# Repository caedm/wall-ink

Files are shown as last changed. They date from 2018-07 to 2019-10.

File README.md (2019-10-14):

# Introduction
Wall-ink was designed from the ground up to be a scalable, [secure](https://github.com/caedm/wall-ink/wiki/Device-security), and completely open solution to display conference room schedules at a university.  The product could, however, be developed to display other images for advertising, directions, staff directories, a weather station, retail pricing, etc.  Currently, the [wall-ink-server](https://github.com/caedm/wall-ink-server) can display schedules from the open source [Booked scheduler](https://www.bookedscheduler.com), any web published iCal file (Outlook / Exchange), and the Google Calendar API.  It can also [rotate through a collection of static images](https://github.com/caedm/wall-ink-server/wiki/Plugin-architecture#static-images-plugin).  With [additional development](https://github.com/caedm/wall-ink-server/wiki/Coding-a-new-plugin), other scheduler integrations or functions are possible.  The hardware simply displays whatever image it is given when it checks in with a wall-ink-server.  Development for putting images on the e-ink screen is made simpler by [allowing the image creation processing](https://github.com/caedm/wall-ink-server/wiki/Wall-ink-image-formats-and-image-handling) to occur on the server side, and not on the device.  Server-side image creation was a design choice for deploying a large fleet of these devices across mulitple buildings.  This way, changes can be made to what the devices are displaying without having to update firmware on dozens or hundreds of devices.  To date, we are aware of several other groups who have successfully written their own server-side software for wall-ink devices in various languages.  Links to other related wall-ink projects are found on the [additional wall ink projects](https://github.com/caedm/wall-ink/wiki/Additional-wall-ink-projects) page.



The original design parameters of this project were to display a room schedule electronically with no wires, at the cheapest possible price point.  No Ethernet, no power wires, in a low-cost footprint.  The resulting project has produced a AA powered WiFi E-ink device for under $100 (US), when parts are purchased in bulk, where the [batteries last a year or two](https://github.com/caedm/wall-ink/wiki/Circuit#batteries).  

The wall-ink project along with the [Wall-Ink-Server](https://github.com/caedm/wall-ink-server) includes everything necessary to build the entire e-ink display system. 

# Summary
The wall-ink project has several components:

* [Circuit and electronics](https://github.com/caedm/wall-ink/wiki/circuit), including Eagle schematic, PCB layout and gerber files
* List of necessary [parts](https://github.com/caedm/wall-ink/wiki/partslist) to build the project
* Arduino IDE [Firmware](https://github.com/caedm/wall-ink/wiki/firmware) for the ESP8266 microcontroller
* CAD files to 3D print the [Case](https://github.com/caedm/wall-ink/wiki/firmware)
* See the [Wall-Ink-Server](https://github.com/caedm/wall-ink-server) project for server side code


# FAQ

## What hardware does wall-ink run on and where do I get it?
The wall-ink project is a hardware, firmware, and software build.  To date, we are not aware of any off-the-shelf commercial products that will do everything that the [wall-ink device](https://github.com/caedm/wall-ink/wiki/7.5%22-Wall-ink-device) does.  There are plenty of ESP8266 devices out there, including ones that sleep, but the hardware as described here is specifically designed to run the wall-ink firmware, sleep, use very little power, fit in the supplied 3D printable case, and update a Waveshare e-ink screen.

## Can I hire you to make the hardware for me?
Due to conflict of interest policies at the University we work for, we are not available for hire to create hardware for you, or to customize software features for you.  That being said, we have uploaded all of the design files and code, and reasonable documentation to do it on your own.  Many people have created this project on their own with positive results.

## What is an ESP8266 and why did you choose that microprocessor?
The [ESP8266 by Espressif Systems](https://en.wikipedia.org/wiki/ESP8266) is similar to an Arduino, but has 10uA deep-sleep function and built-in WiFi with a full TCP/IP stack.  The ESP8266 is also low cost, and fully compatible with the Arduino IDE.  So for under $3, you get a microprocessor that is perfect for this project.

## Why e-ink?  Is it a touch display?
In order to run the device for over a year on a set of AA batteries, we needed to use the lowest power screen possible. Since e-ink screens can hold their image even with the power removed, this is by far the lowest power option out there.  To keep the cost down, the type of [E-ink screens](https://en.wikipedia.org/wiki/E-ink) we chose from Waveshare / Good Display does not have touch screen capability.

## What e-ink screens are supported?
The real limitation of screen resolution support is the RAM available on the esp8266.  Some server-side plugins like the static image plugin and the simple text plugin can handle any screen size dynamically.  Other plugins like the booked and google plugins that use the general scheduling functions are hard-coded for Waveshare 7.5" screens at 640x384 and Waveshare 4.2" screens at 400x300 pixels.  There is currently no support for color displays.  We believe that there would be insufficient memory to support the larger color screens using the current method that the firmware has been coded.  The color screens also take a significant amount of time to update, and the batteries would not last sufficiently long for our use-case, so we did not pursue this option.



## Why does a wall-ink device require a server?
Using a central server for controlling what is displayed on wall-ink devices was a design decision to ease the management of large numbers of devices.  If you only need to manage one e-ink device, running a server component might be overkill, but with dozens or hundreds of devices in the field, it is essential.  Tweaking what is being displayed on 100 or more screens can be done by changing a parameter on a website rather than updating firmware on dozens of devices across the enterprise.  Any wall-ink device pointed to a wall-ink-server can be configured do display ANY image at any time the next time in checks in.  There are also central management features such as looking at error logs, Nagios monitoring, voltage monitoring, and other such high-level tools, all made possible through this architecture.

## Can Wall-ink devices talk to a webserver using https?
The short answer is no.  There are libraries available for an esp8266 to talk to a webserver securely, but [there is not enough RAM onboard](https://github.com/caedm/wall-ink/wiki/Wall-ink-Memory#ram) to run the neccessary encryption code.  If security is a concern, please refer to the wiki articles about [device security](https://github.com/caedm/wall-ink/wiki/Device-security) and [wall-ink server security considerations](https://github.com/caedm/wall-ink-server/wiki/Security-considerations#image-security).

## Will a Wall-ink device connect to enterprise WiFi?
The short answer is maybe.  The ESP8266 WiFi client firmware has been tested to work with WPA2-PSK but does not appear to work with WPA2 Enterprise (including Eduroam). Some enterprises offer an additional "guest" network SSID with limited internal connectivity to handle embedded IOT devices as a solution to this problem.  Before going to the trouble of building this whole project and purchasing a screen, you could purchase an ESP8266 devkit and try connecting to your company's WiFi. 

## What skills and tools  will I need to complete this project?
Some basic electronics experience could be useful if building a [development board prototype](https://github.com/caedm/wall-ink/wiki/development-board-prototype). Building an actual [wall-ink device](https://github.com/caedm/wall-ink/wiki/wall-ink-device) will require some basic soldering and 3d printing, and some electronics experience would be useful to help identify and purchase all the right [parts](https://github.com/caedm/wall-ink/wiki/partslist). The software end of the project will require the use of the Arduino IDE to flash the firmware, and a simple web server to run the [wall-ink-server](https://github.com/caedm/wall-ink-server). The wall-ink-server project has only been tested with Apache, but should work with other server software that supports PHP.

# Getting started
To get a wall-ink device up and running, you will need to build a hardware device and flash it with the latest firmware.  Then you will need to install a [small web service] to host the content for your device to display.  Last, you will need to [configure your new hardware device](https://github.com/caedm/wall-ink/wiki/Admin-mode) to access your wireless network and find your webserver.
## Building the hardware
There are a couple different methods to get started with wall-ink hardware
### Option 1: 
Purchase an esp8266 development board, and a Waveshare e-ink display with HAT and make a [development board prototype](https://github.com/caedm/wall-ink/wiki/Development-board-prototype).  This method will get you up and running quickly with a minimal cost for a proof-of-concept project.  You will be able to power and flash the development board via USB from your computer.  These development boards are designed to be easy to use, but are not meant for battery operated production devices.  The integrated USB to serial chip on the development board alone will drain your batteries in a matter of days.  If you want your device to operate for years on end off of batteries, you will need to build the wall-ink circuit that has been specifically designed for low power draw.



### Option 2:  
Buy all the [loose parts](https://github.com/caedm/wall-ink/wiki/partslist) and solder them to the [printed circuit board](https://github.com/caedm/wall-ink/wiki/Printed-Circuit-Board).  You will also need to [3d print a case](https://github.com/caedm/wall-ink/wiki/7.5%22-Wall-ink-case) for the project.  If you want to start with the real thing, there is no reason why you can't just go straight to it.



## Building and flashing the firmware on to the ESP8266
See the detailed instructions in the [building and flashing firmware wiki article](https://github.com/caedm/wall-ink/wiki/firmware#Building) for instructions on uploading the firmware.

## Install and configure the web server code
See the documentation for the [wall-ink-server](https://github.com/caedm/wall-ink-server) companion project.  If desired, you could write a much simpler server that was not designed for an enterprise as long as it returned files in the correct ["wink format"](https://github.com/caedm/wall-ink-server/wiki/Wall-ink-image-formats-and-image-handling#wink-file-format).  The wall-ink-server project is designed to handle hundreds of devices using various plugins to collect data and present images to the screens.  It includes Nagios monitoring scripts, battery monitors and other tools to handle a large fleet of wall-ink devices.
## Configure the device
Use [Admin mode](https://github.com/caedm/wall-ink/wiki/Admin-mode) to set up the wireless client, the image key, and the URL to get images from.

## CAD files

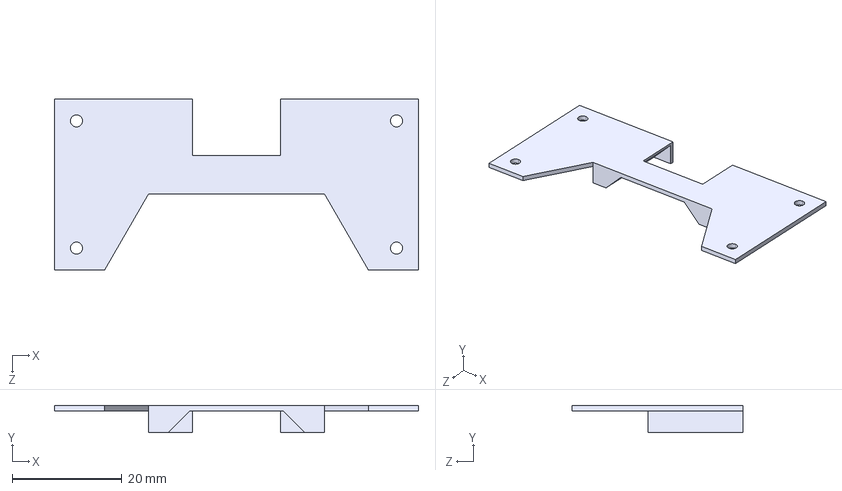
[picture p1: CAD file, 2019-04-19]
case/hat_adapter.STEP
66.2 x 5.00 x 31.1 mm

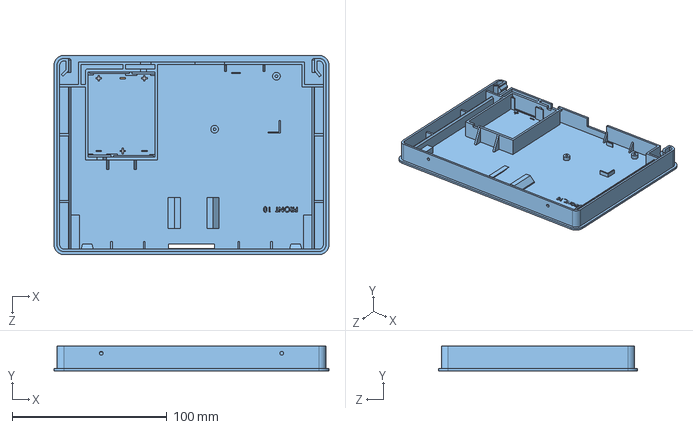
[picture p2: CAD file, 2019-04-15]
case/front.STEP
178.0 x 16.0 x 129.0 mm

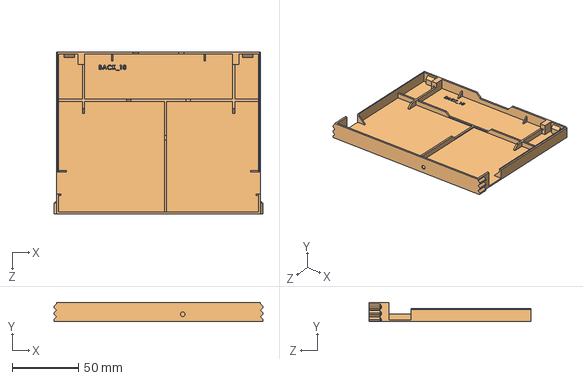
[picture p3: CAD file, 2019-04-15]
case/back.STEP
157.9 x 14.4 x 122.3 mm

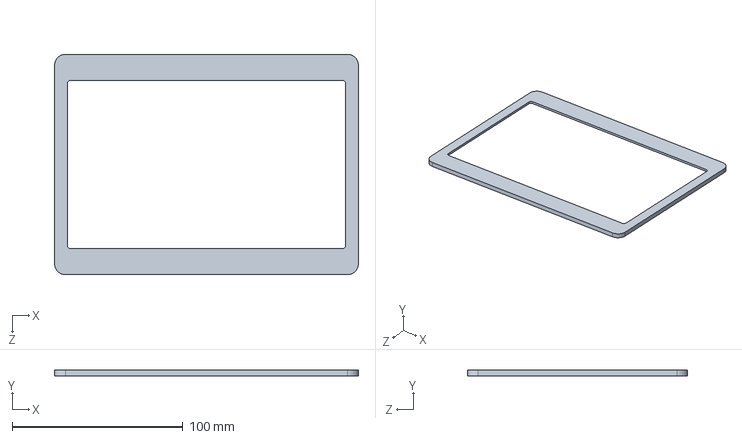
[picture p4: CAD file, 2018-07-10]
case/faceplate.SLDPRT
178.0 x 3.30 x 129.0 mm

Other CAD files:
case/back.IGS
case/back.SLDPRT
case/back.STL
case/faceplate.STL
case/front.IGS
case/front.SLDPRT
case/front.STL
case/hat_adapter.IGS
case/hat_adapter.SLDPRT
case/hat_adapter.STL

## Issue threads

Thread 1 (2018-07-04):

Need to upload hardware

jdeananderson, 2018-07-04:
Need to upload the Eagle Schematic, board layout and gerber files.

AndersenJ, 2018-07-09:
Finished as of 576c2fc

Closed 2018-07-09.

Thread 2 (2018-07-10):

7.5" layout for battery savings

jdeananderson, 2018-07-10:
Feature request:  There is a 4" layout that does not have a time "tick" at the bottom of the screen, and that doesn't update the start time of an event as time progresses.  I would like a 7.5" layout that does the same thing to save updates and therefore battery life.

AndersenJ, 2018-07-10:
This has been implemented on https://github.com/caedm/wall-ink-server

Closed 2018-07-10.

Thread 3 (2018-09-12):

DEFAULT_IMAGE_KEY not writing to memory when changed in Firmware

emdarcher, 2018-09-12:
In the code I changed the value of DEFAULT_IMAGE_KEY in stream_screen.ino, compiled, and re-flashed the firmware with said code. When the device reboots it still uses the old image key. Tested by entering the web interface in admin mode to view the image key. When the image key was changed via the web interface it saved the new key to memory.
Tried rebooting in various ways, including removal and replacement of the battery. Issue persists.
Other values changed, such as ADMIN_PASSWORD are changed correctly when edited in the Firmware code.

AndersenJ, 2018-09-13:
The image key is stored in the EEPROM, which persists even when the ESP8266 is flashed. To clear the EEPROM, run the ```eeprom_clear``` sketch. I added some documentation to the new Troubleshooting wiki page with details about that.

Because I know of know way for the device to know if it's just been flashed, I can't fix this and we'll just need to live with this workaround. Sorry.

Closed 2018-09-13.

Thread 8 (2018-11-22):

Username/password/certificate EAP-TLS support for WiFi

tomuk5, 2018-11-22:
Please add support to upload a certificate or define a username/password to attach to wireless with WPA enterprise.
Allows use in restrictive corporate wireless environments and removes common shares secret for all displays

AndersenJ, 2018-11-26:
Do you need username/password-based WPA Enterprise, or do you need certificate-based WPA Enterprise? Those are two different things, and without knowing your usecase I can't say whether this is possible or not.

From what I understand, there is currently a bug in the binaries provided by Espressif that makes username/password-based WPA Enterprise authentication impossible on the ESP8266. It may be possible to implement certificate-based WPA Enterprise authentication though.

AndersenJ, 2018-12-10:
That's too long without responding; I'm closing this issue. Feel free to open it again later.

tzeeth, 2019-09-22:
Hi! I need to try this with Eduroam too. We want to test the device in a classroom of the University and found this; https://github.com/martinius96/ESP32-eduroam
What do you think? Will it work?
Regards!

AndersenJ, 2019-09-23:
I wish I could say yes, but unfortunately that library is designed for the ESP32, not the ESP8266. It is probably impossible to get it working with Wall-Ink on the ESP8266 due to memory limitations, but it's possible to port Wall-Ink to ESP32. This would require a new PCB to be designed and tested, and it would also likely require some code to be rewritten. We don't currently have the resources to do that. Additionally, when we were doing initial testing, we discovered some problems with the ESP32 platform. It uses about twice as much power (not a deal-breaker, since power usage is still quite low). It's a huge pain to solder (still not a deal-breaker, but annoying). Sometimes, when the ESP32 reboots, [it goes into a bad state and quickly drains the battery](https://github.com/espressif/arduino-esp32/issues/796). We decided this was unacceptable, so we went with the ESP8266.

We use eduroam too, but our devices connect to a guest network. Is it possible that you could do that instead?

tzeeth, 2019-09-23:
Hi @AndersenJ
Really thanks for your fast response. I will ask if they can use a guest network, if they will does any change need to be made?
Regards!

AndersenJ, 2019-09-23:
@tzeeth Sorry, I spoke in error before. The reason we can't connect to eduroam is because of problems with the firmware's implementation of WPA2-Enterprise. The community is [painfully aware](https://github.com/esp8266/Arduino/issues?utf8=%E2%9C%93&q=WPA2+Enterprise) of this issue. It has nothing to do with memory; I got mixed up because memory is what's holding us back from being able to do TLS.

When you say, "Does any change need to be made", what exactly do you mean by that? If you're asking about signing in to the guest network, I don't know. We don't need to here, but that may depend on your school's implementation of the network. As for the sketch, they shouldn't need to change anything apart from entering in the correct SSID and password.

Closed 2018-12-10.

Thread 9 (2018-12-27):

No wakeup after the deep sleep

koos, 2018-12-27:
After a successful setup, I'm realizing that the screen/chip doesn't wake up from deep sleep after the choosen time (in my case 30 min.). Only pressing the 'reset' button forces to get the new image. I'm running the development hardware for now.

jdeananderson, 2018-12-27:
Koos,  after looking over the circuit for the development board prototype on our wiki, I just realized that I left off a very important part of the circuit, the part that makes it wake up on its own!  Thank you for finding this error.  I will update the documentation.  For now, I will tell you that you will need to place a 470 Ohm resistor between GPIO16 and RESET, which on the diagram on our "Development board prototype" page would correspond to  a 470 Ohm resistor between D0 and RST, the top left pin and the pin on the bottom, 3rd from the right.  Thanks again for the question and I believe this will resolve your problem.  Thanks,  --Dean

jdeananderson, 2018-12-27:
Koos,

I was easily able to replicate your problem here, and added the 470 ohm resistor between D0 and RST, which completely solved the problem.  I have fixed the documentation.  Please let me know if this solves your issue and I will close the issue.  Thanks,  --Dean

koos, 2018-12-28:
It worked perfectly. Thanks a lot!

Closed 2018-12-28.

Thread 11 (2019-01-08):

Some Parts Not Available for Given Link

philipbl, 2019-01-08:
Two items in the part list can no longer be found using the provided links:

Micro JST PH 2.0 2Pin Right-Angle Socket Male and Connector Female w./ wire
https://www.ebay.com/itm/202013987748

JST_PH 2.0mm Pitch 8-pin double end female cable
https://www.ebay.com/itm/192369804646

It would be great if we could get a new link with an equivalent part.

Thanks!

jdeananderson, 2019-01-08:
I have updated the links.  Thanks.

philipbl, 2019-01-08:
Thanks!

Closed 2019-01-08.

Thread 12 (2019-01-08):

Device sometimes boots into AP mode instead of STA mode

AndersenJ, 2019-01-08:
Sometimes, the devices  boot themselves into AP mode instead of STA mode. This likely wastes battery, and seems like it might be related to some connection problems we're experiencing.

AndersenJ, 2019-01-10:
This should be fixed now as of b282f65b1503718a8518eab7722d750f9166dbeb.

Closed 2019-01-10.

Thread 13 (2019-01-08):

Some devices suddenly not connecting to WiFi

AndersenJ, 2019-01-08:
Some of these devices are having serious problems reliably connecting to WiFi. They seem to establish a connection, then disconnect without getting an IP address. I think it may be related to this issue: https://github.com/esp8266/Arduino/issues/3630

AndersenJ, 2019-01-09:
This turned out to be related to DHCP issues that were not caused by code in this repository.

Closed 2019-01-09.

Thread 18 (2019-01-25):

Error Code is sometimes 4294967295

AndersenJ, 2019-01-25:
Sometimes, the error code is listed as 4294967295. I have no idea why.

This happened once when the base url was mis-entered as http://wallink/.groups.et.byu.net/get_image.php.

AndersenJ, 2019-01-25:
I found roughly 20 instances of this happening in our logs from roughly a dozen different devices. There doesn't seem to be much explanation as to why this happens, so the only way I can imagine I'll learn anything is by hooking the device up via serial and logging the filtered output into a file. It may be that some part of the URL other than the base URL is being malformed, but it isn't immediately obvious how that might be happening.

AndersenJ, 2019-02-13:
I've found that this happens much, much more frequently on some devices than on others. Also, I got the following debug information over serial:

```
http://wallink.groups.et.byu.net/get_image.php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
[HTTP] begin...
[HTTP] GET...
[HTTP] GET... failed, error: connection refused
```

There was some other stuff, but this seemed to be most relevant.

Pillmayr, 2019-04-11:
Is it possible that the problem occurs when the web resource takes too long to create the archive?
My demo installation with static content (Hard coded ICAL File) works perfectly on the devices.
When I dynamically load the iCal externally, I get the same error from time to time.

AndersenJ, 2019-04-11:
I think it's possible that that could trigger the error, but I don't think it's the problem in this case. We have roughly 50 of these things running right now, and one of them gets this error more often than all the rest combined - about 2 dozen times per day. I switched it to the static images plugin to test this though; I'll get back to you tomorrow, if I remember.

Pillmayr, 2019-06-27:
For you... i've implemented an own version of the "image" server (php with laravel -> inspired by https://github.com/bajensen/wall-ink-php) so that the ical data for the calendars are prefiltered & cached by a cronjob. during my work on the server, i found out, that the ical files are quite big, as the ical file contains all the calendar data, even the data in the past. In my case, I had a high-traffic meeting room, where many meetings have already taken place. The ICal File has about 1,8mb (!!). I download the file in advance and save the filtered version of the data so that I only have to handle the data of "today", when the wall-inks connects to download the image-archive.
This almost eliminates the problem.

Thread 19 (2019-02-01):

Don't log voltage data for screens that haven't recently checked in

AndersenJ, 2019-02-01:
Right now, the tool that's populating our rrd databases is just assuming that whatever information is in the database is up-to-date. It shouldn't be re-entering old values over and over again, but it currently is.

AndersenJ, 2019-02-01:
Whoops, wrong project.

Closed 2019-02-01.

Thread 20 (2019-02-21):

New Waveshare e-paper HATs will not warm boot.

jdeananderson, 2019-02-21:
For some reason, the new Waveshare e-paper hats will not let a wall-ink device boot unless power is removed completely first.  This means that it will not wake-up from deep sleep on it's own, and it won't go into Admin mode without removing the power and restoring power.  Hitting the reset button will cause the light to blink, but it won't go into admin mode.  Removing the Waveshare hat allows the wall-ink device to check in with the web server without any issues.  Replacing a new hat with an older model hat also fixes the issue.  The newer hats have a lever that runs the length of the connector on the back to clamp the small ribbon cable.  The older hats have a plastic slider with tabs that sits under the ribbon cable.  I will be looking into this issue this week.

jdeananderson, 2019-02-21:
This has been isolated to any esp8266, including a development board, when hooked to a new Waveshare Hat AND the reset pin is hooked to GPIO16 through a 470 ohm resistor.  Everything works fine with the old Hats,  and everything works fine with the new hat if GPIO16 is not pulled down to ground through a 470 Ohm resistor.

jdeananderson, 2019-02-21:
As referenced in this discussion:  https://github.com/universam1/iSpindel/issues/59, GPIO16 to RST can be tricky to keep reliable.  the 470 Ohm resistor is very reliable with the old hat with the TXS0108E chip, but not with the new hat that uses the TXB0108 chip.  I have started preliminary testing with a diode and it appears promising.

jdeananderson, 2019-02-21:
After a bit of study and consulting a couple of EE's, I have ordered a package of Shottky diodes.  We decided that the only way to make a resistor reliable was with an external pull-up circuit with how the ESP8266 works.  We have investigated how a Shottky diode would work in the circuit, and we believe it will work.  I'm going to replace the 470 Ohm resistor in 5 units and run them for a week and see if they miss any check-ins.

jdeananderson, 2019-03-12:
This is still an open issue.  I have not been able to focus on this problem, but have renewed efforts today.  It appears that the shottky diodes do not magically solve this problem.  I will investigate further as time allows.  The old HATs seem to still be just fine in our production systems, but the new ones will still not wake from deep sleep.  I have a dev board working with a shottky diode, but the wall-ink pcbs will not come out of deep sleep with a shottky diode.  I'm hitting the breadboard again to figure out what is going on.

jdeananderson, 2019-03-19:
It appears that this has everything to do with which GPIO pins are used, and most likely GPIO0 and GPIO2.  The other strange thing that happens now is that the LED on the ESP8266 stays on for great lengths of time draining the batteries.  One combination that is reproducible is if RST is hooked to GPIO2, when in deep sleep the LED comes on.  When you unhook RST, the light goes off.  Hook GPIO2 back to RST and it comes back on.

Here are some GPIO mappings that have been tried with varying success.

WSS = WaveShare Suggested (from their documentation)
WSD = WaveShare Device, their embedded esp8266 device on a epaper hat
WI0.9 = Wall-ink PCB version 0.9
try1 = a new mapping that seems to boot regularly.

WSS seems to boot every other time.  WI0.9 boots only on cold boot.  Try1 seems to boot every time, but still has an issue with the LED staying on for extraordinarily long times during deep sleep.  The investigation will continue as time allows.

Pin order: 3v3 GND DIN CLK CS DC RST BUSY
WSS: 3v3 GND 13 14 15 0 2 4
WSD: 3v3 GND 13 14 15 4 5 16
WIv0.9: 3v3 GND 13 14 5 0 2 12
try1: 3v3 GND 13 14 15 5 2 4

Notes:

CS was changed to GPIO5 on WIv0.9 because the device would not boot reliably out of deep sleep with pin 15 used for CS.  Changing it to the "non-standard" GPIO5 seemed to clear up all of the trouble.  Running 50 of these things constantly for months has proved this to be very stable with the old WaveShare Hats.

The WaveShare device uses GPIO16 for busy.  On the Wall-ink device, we are using GPIO16 to bring the device out of deep sleep an investigation would have to be done to know if GPIO16 could be re-used reliably.

jdeananderson, 2019-03-29:
I have verified that the issue is with the new Waveshare hats, and can no longer recommend using the Waveshare hats.    I have purchased a couple of hats, or driver boards from GooDisplay, and they work perfectly.  This is going to require a re-design of the hardware which will be forthcoming.

This is the driver board:
http://www.buy-lcd.com/index.php?route=product/product&product_id=58595

This "hat" or driver board does not contain the voltage buffering circuit on the Waveshare displays that ensure that 5v signals from an Arduino do not damage the screen.  Since the esp8266 uses 3.3v signalling, we don't need that additional chip-- which seems to be causing issues anyway.  Going forward we are going to base our designs around the less expensive GooDisplay DESPI-C02, even though it has less convenient wire terminals.  Updates will be coming to the 3D printed cases and so forth.  The new cases will need to be compatible with the old backs such that new fronts will fit seamlessly with old backs that are already installed on the walls of buildings.

AndersenJ, 2019-04-15:
New cases are pushed to master, but I haven't finished tweaking the adapter to use the new HATs with the old cases yet.

AndersenJ, 2019-04-19:
The adapter to use the new HATs with the old cases has been pushed to the master branch. Now we just need to finish documenting our changes and we can close this ticket.

Pillmayr, 2019-06-14:
Just to be sure: Can I use the GooDisplay DESPI-C02 Hat with the Waveshare E-Ink 7,5 Inch Displays?
Thx

jdeananderson, 2019-06-14:
Yes, the DESPI-C02 works great with the 7.5" black and white displays!  I have built it on a breadboard and it works perfectly. I am waiting for some new boards to come from China so I can build a real device, take pictures and update the documentation.  Since the DESPI-C02's use a different cable interface, I updated the board to use a different cable since I couldn't find a cheap cable that would work.  I should have an update in a week or so.  Thanks!

Pillmayr, 2019-06-14:
Thank you...
I plan to use the cable that comes with the Waveshare Kit (individual wires) anyway. It may be a bit chunky, but it should (hopefully) work.

jdeananderson, 2019-06-14:
I have done the exact same thing, but I have not been able to find that same cable for sale as a solution to purchase outside of the kit.  When you buy just the screen, you don't get that cable, so I wanted to come up with a cheap solution of all easily found off-the shelf parts.  You should be good to go!  If you get something working, send me a picture and I will put a "make" of it on our site if you'd like.  Thanks!

Pillmayr, 2019-06-25:
Hello,
I got the hats today, and the first tests are going well.
but I do not know how the hat adapter should be mounted. either I printed it wrong or it is too small.
I've now screwed the adapter upside down, so it fixes the board and the board no longer slips.
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

jdeananderson, 2019-06-25:
When we got the new hats we had to figure out a way to mount them.  I'm still waiting of a shipment of boards from China to document the final revision of the re-make, but this is more-or-less how it will work.  We had to make a new front with the batteries rotated to make everything fit.
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
The plastic "butterfly" piece was meant for what you are doing there, but the other way up with the bevels pointed down to hold the hat in place like this:

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

I realize there isn't room for your cables, but this was only meant for if we had a unit already built that the existing hat died and the unit was already assembled and needed to be retro-fitted.  Our plan if this unfortunate situation arose was to unsolder the pin headers off the hat and solder the cable directly in so it would fit.  Not ideal, but I was hoping it would never have to do one.  That's why Jonathan made the new layout as seen on GitHub.  If you re-download the parts, you won't need the hat adapter, and there will be room for your cables.

I hope this makes sense, and you can get it working.  Sorry for the confusion.  I hope to have all the parts in the next week or so and update all the documentation so it is much more straight forward.

junleus, 2019-08-17:
question:
what pin order if use DESPI-C02

Pin order: 3v3 GND DIN CLK CS DC RST BUSY
WSS: 3v3 GND 13 14 15 0 2 4
WSD: 3v3 GND 13 14 15 4 5 16
WIv0.9: 3v3 GND 13 14 5 0 2 12
try1: 3v3 GND 13 14 15 5 2 4

matyasforian, 2019-09-27:
Sorry it's not clear to me, which is the recommended display & hat now?
GooDisplay DESPI-C02 Hat with Waveshare E-Ink 7,5 Inch Display? Are other parts of the part list up to date with this spec?
Thanks

jdeananderson, 2019-09-27:
Yes, the GooDisplay DESPI-C02 Hat with the Waveshare E-ink 7.5 inch display works perfectly.  The new Waveshare HATs do not work reliably.  As far as the rest of the parts go, everything else is still current, but the problem is a good way of connecting the wiring between the DESPI-C02 and the board.  I have a solution and have bought the parts to work it up and document it, but I have been buried in projects.  It just needs to get done and I will do it either this afternoon or Monday.  I will update the parts list when I get the new pictures up in the next few days.  Thanks for asking, and thanks for your patience.

AndersenJ, 2019-10-17:
In case anyone was wondering where this issue is, we discovered we don't currently have the parts to build the new board. We have the PCB, just missing some miscellaneous parts. We'll get this updated once we've ordered the parts and actually put it together.

AlexandreBlais42, 2024-05-01:
I was able to adapt the circuit to make it work with the new HAT (Rev 2.2) by changing R1 to 100 Ohms and R8 to 470 Ohms. It was able to warm boot for the whole night.

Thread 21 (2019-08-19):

wall-ink-server running https

zhongshanliyu, 2019-08-19:
when wall-ink-server running https, the wall-ink get error message when get https://example.com/get_image.php.

zhongshanliyu, 2019-08-19:
there are a example to showing the HTTPSRequest, i thiank that can solve the issue.

https://github.com/esp8266/Arduino/blob/master/libraries/ESP8266WiFi/examples/HTTPSRequest/HTTPSRequest.ino

zhongshanliyu, 2019-08-19:
error code wall-ink-server logs below

Firmware: 4.02a Width: 640 Height: 384 Voltage: 2.85 Error Code: 4294967295 Plugin: 1

Pillmayr, 2019-08-19:
Hello. As you said before briefly: The firmware does not use the Secure Client but the normal Wifi client. I would simply customize the firmware in your place and use the Secure Client instead of the normal client: https://github.com/caedm/wall-ink/blob/master/stream_screen/stream_screen.ino#L730
The second option would be to instantiate the client based on the protocol. But I think that the first variant is more pragmatic and faster to implement, because all of your endpoints are running on HTTPS anyway, right?

jdeananderson, 2019-08-19:
We investigated using an https client, but if I remember correctly there was not enough free memory in the sketch on the esp8266 to support it.  Perhaps Johnathan remembers?

zhongshanliyu, 2019-08-20:
> Hello. As you said before briefly: The firmware does not use the Secure Client but the normal Wifi client. I would simply customize the firmware in your place and use the Secure Client instead of the normal client: https://github.com/caedm/wall-ink/blob/master/stream_screen/stream_screen.ino#L730
> The second option would be to instantiate the client based on the protocol. But I think that the first variant is more pragmatic and faster to implement, because all of your endpoints are running on HTTPS anyway, right?

correct, wall-ink-server running internet, and wall-ink get https url will encrypt the mac address etc.

zhongshanliyu, 2019-09-07:
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
that true, memory not enough to running.

Closed 2019-09-07.

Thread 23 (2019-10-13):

Devices for sell

al-indigo, 2019-10-13:
I'm dumb at electronics but I really want to have 10 devices for https://www.ispras.ru/en/ .

Do you have an option to sell me spare devices or to make them for some money with shipping to Moscow? If you do, what could be the cost? I suppose the case we would print ourselves, but the main part could take a lot of time.

AndersenJ, 2019-10-16:
Sorry about this, but after some internal discussion we decided we aren't able to do this for you. I'm sure you could find someone local who could help you with it though!

Closed 2019-10-16.

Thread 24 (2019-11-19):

GxGDEW075T7 got Image or password failed verification test

zhongshanliyu, 2019-11-19:
Per GxGDEW075T8 end of life, I am trying to get GxGDEW075T7 working in wall-ink device.

- GxGDEW075T7  driver copy from  ZinggJM/GxEPD Version 3.0.9 to caedm/GxEPD

- ESP8266 version2.6.1

- GxGDEW075T7.h     -->    #define GxGDEW075T7_PAGES 2

- stream_screen.ino    -->
 #define ROTATION = 0  showing below
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

 #define ROTATION = 2 showing below

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

GxGDEW0583T7 and GxGDEW075T8 running good, so I confirmed server and Adruino setup are correct.

Debug below

`[HTTP] begin...
[HTTP] GET...
Time in milliseconds: 33862
File Size: 48068
remote timeHash:
b42af630fcd9d5c4443fbe9a1f35322f8dad17cc
local timeHash:
b42af630fcd9d5c4443fbe9a1f35322f8dad17cc

Updated currentTime: 1574205505
Updated nextTime: 1574206230
Old imageHash: ffffffffffffffffffffffffffffffffffffffff
New imageHash: d586842c4c32602568bd24c852814b7b855f28c2
Initializing display; time in milliseconds: 33885
Display initialized; time in milliseconds: 34128
state: 5 -> 0 (0)
rm 0
del if0
usl
mode : null
force slp enable,type: 2
fpm open,type:2 0
Calculating SHA1 hash
Time in milliseconds: 36003
local image hash:
18f0581b86ca778b683725ea3e58fc8bc491e5d

local hash with everything:
28ec2aa14d5ea7c6e9fedfb1295fd8bc12e126e

Image or password failed verification test, sleeping
Time in milliseconds: 36035
fpm close 3
force slp enable,type: 2
fpm open,type:2 0
Measuring Voltage...
Time in milliseconds: 36330
Voltage: 2.88
Time in milliseconds: 36331
Image failed verification test
`

zhongshanliyu, 2019-11-19:
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

zhongshanliyu, 2019-11-20:
updated, when I ignore the imageVerified, got half of the screen shows.
that should be cause by GxGDEW075T7.h --> #define GxGDEW075T7_PAGES 2

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

AndersenJ, 2019-11-20:
This project doesn't currently support partial updates. We may choose to support this feature in the future, but for the most part we're just maintaining the features we already have at the moment.

The problem with partial updates is that if you're only updating half the screen at a time, the image verification will only hash half the image and the hashes won't match. I did some quick math though, and it looks like partial updates are our only option for the screen as long as we're using the ESP8266.

I thought about how I would do this, and I came up with something: When the device sends its request to the server, it would include a number that indicates how many pages the image should be split into, and which page is being asked for. The device would need to send multiple requests, which is not a huge deal. There are also some other far fancier solutions we could implement. The real problem is, like I said, we're mostly supporting our existing features right now. We may never get to actually implementing this. In the meantime, if someone else does, we'd probably accept their pull request.

Is gooddisplay going to stop making GxGDEW075T8 displays? Are the physical dimensions of the GxGDEW075T7 at least the same? It would be a pain if we had to design a new case. How fast does the new screen update?

zhongshanliyu, 2019-11-20:
I confirmed from Gooddisplay, and there only 10 inventory of GxGDEW075T8. Waveshare as vendor of Gooddisplay. GxGDEW075T7 physical dimensions same as GxGDEW075T8, with 800x480.

jdeananderson, 2019-11-20:
How fast can the new T7 update the display?  Does it take about the same amount of time as the old T8, or is it faster?  We are concerned about engineering a solution that minimizes battery utilization.

zhongshanliyu, 2019-11-20:
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

jdeananderson, 2019-11-20:
Thanks for looking that up...  it looks like it will still be 4 seconds.  So this puts us in a difficult situation, as AndersenJ explained earlier.  There is not enough RAM on the esp8266 to download the entire 800x480 image to display it.  The 640x384 image uses about 32K of RAM to store, and the new image at 800x480 is 48K.   The esp8266 only has 80K of RAM, and 40K of it are used with the Espressif SDK for WiFi and TCP/IP functionality.  Of the 40K left, the 640x384 image used 32K of it.
Andersen J suggested splitting the image into two 24K chunks to solve this problem, but I'm hoping to perhaps we can figure out a way to have the SDK use less space...

This thread https://github.com/espressif/ESP8266_NONOS_SDK/issues/238 suggests that a user who was facing a similar issue with a different ESP8266 project was able compile his project with 60k of free memory.  AndersonJ and I will have to look this over and see if this is even possible and get back to you.

AndersenJ, 2019-11-26:
Unfortunately, this is unlikely to work for us.

zhongshanliyu, 2019-11-26:
yeah, let close it then. thank you.

AndersenJ, 2019-11-26:
Thanks for reporting this, it's really good for us to know about this.

Closed 2019-11-26.

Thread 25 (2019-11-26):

Find alternative for e-ink screens

AndersenJ, 2019-11-26:
As described in https://github.com/caedm/wall-ink/issues/24, the screens we're currently using aren't likely going to be easy or even possible to purchase in the future. We'll need to find a replacement screen. We may need to change some code (or in the worst case, the case) to accommodate that new screen choice.

ljorzick, 2020-07-26:
Is the v.2 of the originally used waveshare display an alternative? https://www.waveshare.com/wiki/7.5inch_e-Paper_HAT
Should be compatible in terms of hardware, but will require a code change due to changed resolution...or are we hitting memory boundaries on the ESP with the increased resolution (seen this mentioned in the project somewhere).
Background: I'm considering this as a student project for a course at my school, but am currently looking to source parts for a proof of concept and couldn't source the original display...

AndersenJ, 2020-07-26:
It's hitting memory boundaries. The ESP8266 doesn't have enough RAM for this. That said, I think this screen does support partial updates. This means you could modify the firmware and server software so it pulls down only half of the image at a time. This would probably not be too difficult.

ljorzick, 2020-08-02:
Hmm,
I'm more of a networking guy with not much in-depth knowledge in terms of coding. Are you investigating any replacement options which will work with the project ootb or is there any perspective in that regard? Thanks for your time and effort, the project looks amazing :-)

AndersenJ, 2020-08-03:
I actually don't work for CAEDM anymore so I can't speak for them, but I'm fairly sure that finding a replacement option is a very low priority for them right now. It may actually never happen. I may decide to give it a try on my own time in a few months though, just for fun.

DIYglenn, 2023-10-04:
How much work would it be to make it work with ESP32? It should solve both this issue, and could give both better security functionality and possibly color options. Color could work as long as they support partial updates, otherwise some are really slow.

AndersenJ, 2023-10-05:
It's quite doable to make it work with the ESP32, and it would indeed solve the issue, but it also introduces a new issue: the ESP32 doesn't consistently wake from sleep. Sometimes instead of waking properly, it'll just go into a state where it drains the batteries while doing nothing. Here's some detail: https://github.com/espressif/arduino-esp32/issues/796

That said, it's been a while since anyone worked on this. It's certainly possible that there's some other new product that would work better.

DIYglenn, 2023-10-06:
That's true. But it does open for a lot of possibilities for devices connected to power, (mains or PoE f.ex).
Then you'd have partial update possibilities etc. So while it does consume more electricity, and is not as flexible to install as before, you'd still have an extremely low draw for an always on screen.

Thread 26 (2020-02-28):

Upgrade to ESP32?

oldjohngalt, 2020-02-28:
I am new to this, but with the memory limitations to the higher resolution 7.5 displays would it be feasible to switch to the ESP32?  This extra memory should help allow https for increased security and allow compression which may decrease the download time.

There seems to be some work being done at https://github.com/martinberlin/eink-calendar with the ESP32 and newer E-Ink Screens.

jdeananderson, 2020-02-28:
We originally wanted to use the ESP32 for this project for all of the reasons you stated.   We even made a prototype and got it working... unreliably.  The ESP32 has a bug where it occasionally doesn't wake from deep sleep.  See https://esp32.com/viewtopic.php?f=12&t=12690.  We tried to make the ESP32 work, but we simply couldn't get it to wake up reliably.  When this bug in the ESP32 is fixed, we can work to move the project to the ESP32.  Moving the code over should not be that big of a deal. I just checked, and as of 8 days ago the deep sleep bug was still active.

We built these devices for use in an enterprise, with 80+ devices deployed across several buildings and didn't want to deal with devices locking up and not booting.  Thanks for the suggestion, and I hope that we can go down that path soon.  Unfortunately, that bug has been around for two years and there does not seem to be a fix coming soon.  I could easily see a newer processor replacing the ESP32 being released before this bug is fixed.  We shall see, and I hope I am wrong...

Closed 2020-02-28.

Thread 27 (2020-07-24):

Having problems with fiting "hat_adapter" to front plate

elmiba, 2020-07-24:
Hi,

I have a quick question about the hat adapter. I have printed the case you designed and I can't find a way to slide the hat adapter onto the front of the case.

I have searched or this problem and also looked at it in CAD but it somehow does not want to fit. I think I have read about a similar issue some time ago, but I could not find it again.

Thanks for your advice, in advance.

Cheers

jdeananderson, 2020-07-27:
Without knowing which case and hat adapter you are using, it is hard to know what is going on.  There are some updated pictures on the issue https://github.com/caedm/wall-ink/issues/20

This is a picture of using one of the new hats, and the case that goes with it.
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

This is a picture of using an older case, and one of the newer hats along with a hat adapter.
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

For the most part, interest in this project has disappeared since the original 7.5" screen that the project was developed for is no longer available, and the new screen that was released requires more memory than the ESP8286 can provide, without a serious re-write.  My employer is not in a position to allow us to put that kind of effort into this project at the moment, but you are welcome to fork the project and make the modifications yourself.  Good luck!

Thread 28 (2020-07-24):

Ebay link is down

elmiba, 2020-07-24:
Hi,

I just wanted to point out that this Ebay link is down: https://www.ebay.com/itm/322992751056
This should be for the cable between driver board and esp board.

regards

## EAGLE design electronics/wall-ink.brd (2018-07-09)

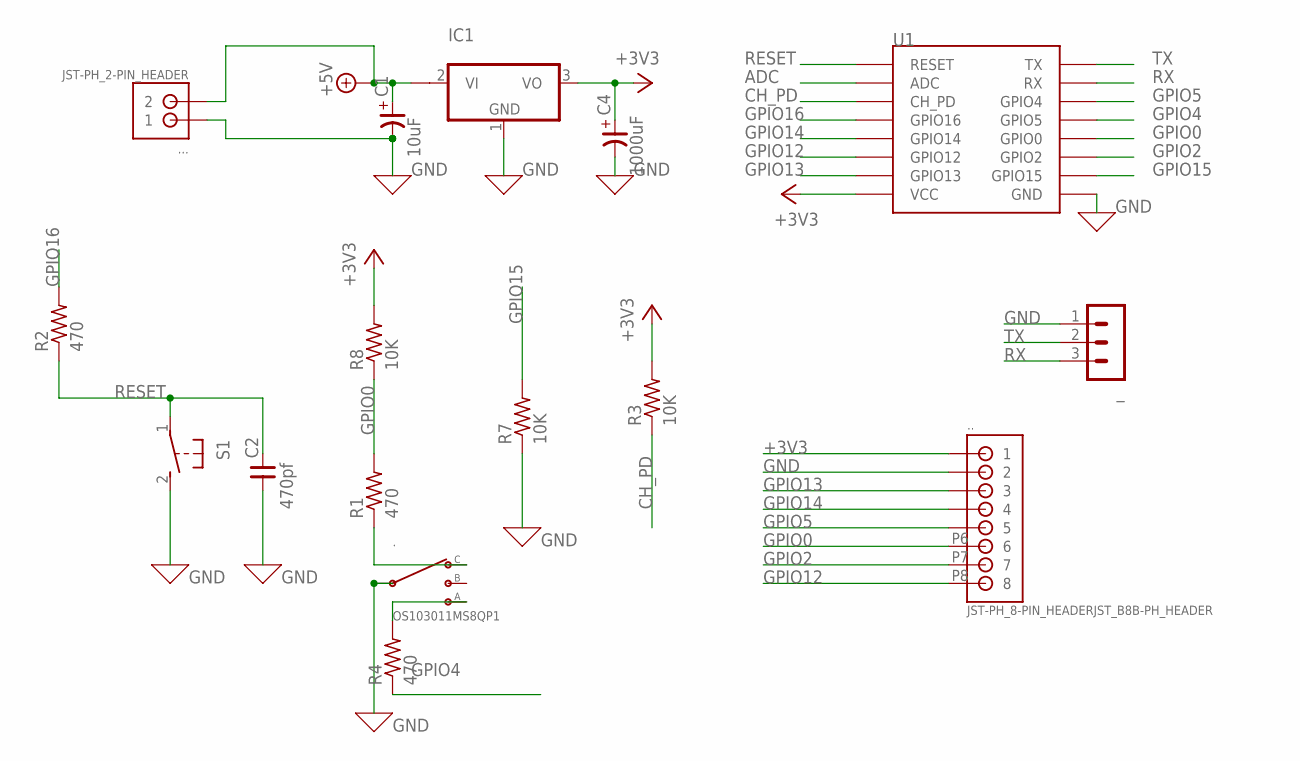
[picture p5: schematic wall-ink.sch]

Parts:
.: OS103011MS8QP1; OS102011MS8QP1
..: JST-PH_8-PIN_HEADERJST_B8B-PH_HEADER; JST_B5B-PH_HEADER
...: JST-PH_2-PIN_HEADER; JST_B2B-PH_HEADER
C1: 10uF; E-020X050
C2: 470pf; C025-040X018
C4: 1000uF; E-050X100
IC1: MCP170312MB; SOT89
R1, R2, R4: 470; 0204/5
R3, R7, R8: 10K; 0204/5
S1: 31-XX; B3F-31XX
U1: ESP12SMD; ESP12-SMD
_: MA03-1

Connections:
+3V3: ...P1 (1), C4.+, IC1.3 (VO), R3.2, R8.2, U1.VCC
+5V: ....P2 (2), C1.+, IC1.2@1 (VI1)
ADC: U1.ADC
CH_PD: R3.1, U1.CH_PD
GND: ..2 (C), ...P2 (2), ....P1 (1), C1.-, C2.1, C4.-, IC1.1 (GND), R7.1, S1.2 (S), U1.GND, _.1
GPIO0: ...P6 (6), R1.2, R8.1, U1.GPIO0
GPIO2: ...P7 (7), U1.GPIO2
GPIO4: R4.1, U1.GPIO5
GPIO5: ...P5 (5), U1.GPIO4
GPIO12: ...P8 (8), U1.GPIO12
GPIO13: ...P3 (3), U1.GPIO13
GPIO14: ...P4 (4), U1.GPIO14
GPIO15: R7.2, U1.GPIO15
GPIO16: R2.2, U1.GPIO16
unnamed: ..4 (3), R1.1
unnamed: ..1, R4.2
RESET: C2.2, R2.1, S1.1, U1.RESET
RX: U1.RXD0 (RX), _.3
TX: U1.TXD0 (TX), _.2

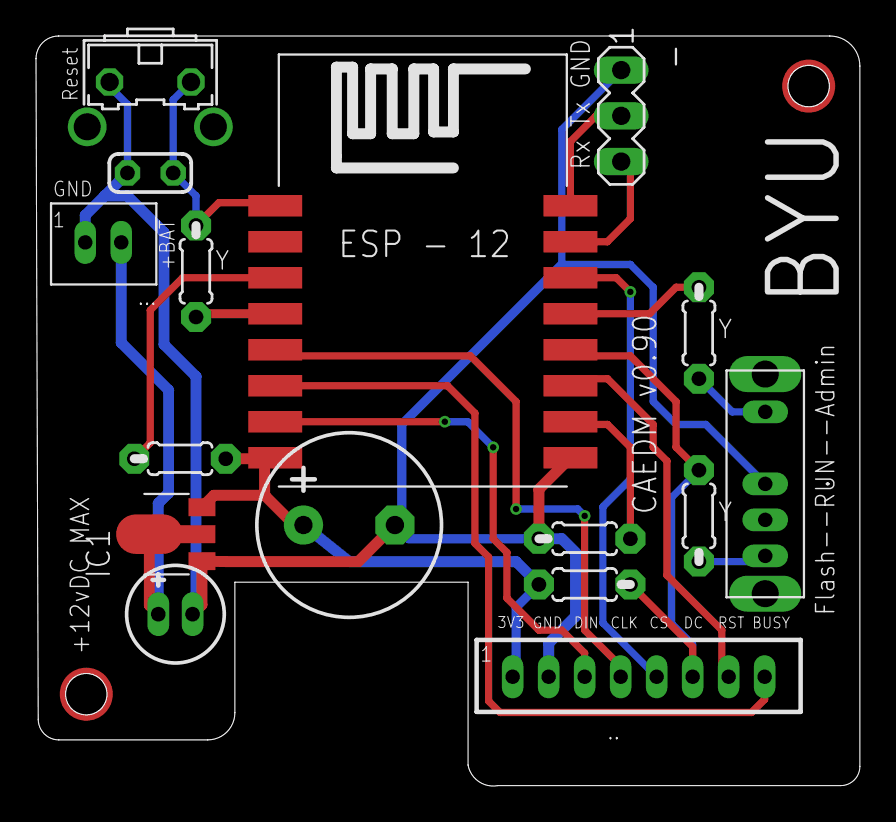
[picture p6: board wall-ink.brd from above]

Board: 2 copper layers, 45.8 x 41.7 mm, 16 parts (0 on the bottom side), 18 nets.

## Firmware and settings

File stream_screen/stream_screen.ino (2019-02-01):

//Sketch uses esp8266 board version 2.4.2
//Sketch uses the GxEPD library from https://github.com/ZinggJM/GxEPD
//The GxEPD library needs to be modified such that display._buffer is public instead of private. This needs to be done for the driver of each screen type you want to support.
//You may notice that this program has a few memory leaks. Those were left there on purpose, since the device reboots so often.

#include <GxEPD.h>
#include <Hash.h>
#include "debug_mode.h"
#include "credentials.h"
#include <pgmspace.h>
#define FIRMWARE_VERSION "4.02a"
#define BASE_URL "http://example.com/get_image.php"
#define DEVICE_TYPE 2
#define ADMIN_MODE_ENABLED 1
#define MAX_SLEEP 3600
#define MIN_SLEEP 10
#define ONE_DAY 86400
#define ONE_HOUR 3600
#define INITIAL_DRIFT_SECONDS 30
#define DEBUG_ON_BY_DEFAULT false
#define WIFI_PROFILE_1_ACTIVE_BY_DEFAULT true

extern "C" {
#include "user_interface.h"
}

#if DEVICE_TYPE == 1
#define X_RES 400
#define Y_RES 300
#define ROTATION 0
#include <GxGDEW042T2/GxGDEW042T2.cpp>      // 4.2" b/w landscape
#elif DEVICE_TYPE == 2
#define X_RES 640
#define Y_RES 384
#define ROTATION 2
#include <GxGDEW075T8/GxGDEW075T8.cpp>      // 7.5" b/w landscape
#endif

#include "admin_mode.h"

#include <GxIO/GxIO_SPI/GxIO_SPI.cpp>
#include <GxIO/GxIO.cpp>

#include <Fonts/FreeMonoBold9pt7b.h>

GxIO_Class io(SPI, 5, 0, 2);
GxEPD_Class display(io, 2, 12);

#include <ESP8266WiFi.h>
#include <ESP8266WiFiMulti.h>
#include <ESP8266HTTPClient.h>
#include <EEPROM.h>
#include <ESP8266WebServer.h>

ADC_MODE(ADC_VCC);  //needed to read the supply voltage

ESP8266WiFiMulti WiFiMulti;

ESP8266WebServer server(80);

// CRC function used to ensure data validity
uint32_t calculateCRC32(const uint8_t *data, size_t length);

//number of failed attempts to connect to wifi
uint16_t attempts = 0;

// Structure which will be stored in RTC memory.
// First field is CRC32, which is calculated based on the
// rest of structure contents.
// Any fields can go after CRC32.
// Must use a multiple of 4 bytes of RAM.
struct {
    uint32_t crc32;
    uint32_t currentTime;
    uint32_t nextTime;
    uint32_t elapsedTime;
    int32_t driftSeconds;
    uint32_t consecutiveCrashes;
    uint8_t channel;  // 1 byte,   5 in total
    uint8_t bssid[6]; // 6 bytes, 11 in total
    uint8_t padding;  // 1 byte,  12 in total
    char ssid[20];
    char password[20];
    char imageHash[20];
    uint32_t errorCode;
} rtcData;

struct {
    bool wifiProfile1Active;
    char baseURL[100];
    char ssid0[20];
    char ssid1[20];
    char password0[20];
    char password1[20];
    char imageKey[20];
    bool debug;
    uint8_t hash[20];
} eeprom;

String url = "";

bool readEeprom() {
    EEPROM.begin(sizeof(eeprom));
    EEPROM.get(0, eeprom);
    EEPROM.end();
    uint8_t hash[20];
    sha1((uint8_t*) &eeprom, sizeof(eeprom)-20, hash);
    bool dataCorrupted = false;
    for (int i = 0; i < 20; i++) {
        if (eeprom.hash[i] != hash[i]) {
            dataCorrupted = true;
        }
    }
    return !dataCorrupted;
}

void writeEeprom() {
    sha1((uint8_t*) &eeprom, sizeof(eeprom)-20, eeprom.hash);
    EEPROM.begin(sizeof(eeprom));
    EEPROM.put(0, eeprom);
    EEPROM.end();
}

String getMAC() {
    String mac = WiFi.macAddress();
    while(mac.indexOf(':') != -1) {
        mac.remove(mac.indexOf(':'), 1);
    }
    return mac;
}

void setURL() {
    url = eeprom.baseURL;
    url += "?mac_address=";
    url += getMAC();
    url += "&firmware=";
    url += FIRMWARE_VERSION;
    if (eeprom.debug) {
        url += "_debug";
    }
    url += "&error=";
    url += rtcData.errorCode;
    url += "&width=";
    url += X_RES;
    url += "&height=";
    url += Y_RES;
    url += "&voltage=";
    if (eeprom.debug) {
        Serial.println("Measuring Voltage...");
        Serial.print("Time in milliseconds: ");
        Serial.println(ESP.getCycleCount() / 80000);
    }
    float volts = 0.00f;
    volts = ESP.getVcc();
    url += String(volts/1024.00f);
    if (eeprom.debug) {
        Serial.print("Voltage: ");
        Serial.println(volts/1024.00f);
        Serial.print("Time in milliseconds: ");
        Serial.println(ESP.getCycleCount() / 80000);
    }
}

void crash(String reason) {

    ++rtcData.consecutiveCrashes;

    //set sleep time here
    uint32_t sleepTime;

    switch(rtcData.consecutiveCrashes) {
        case 1:
            sleepTime = 60*1;
            break;
        case 2:
            sleepTime = 60*5;
            break;
        case 3:
            sleepTime = 60*15;
            break;
        case 4:
            sleepTime = 60*30;
            break;
        case 5:
            sleepTime = 60*30;
            break;
        case 6:
            sleepTime = 60*30;
            break;
        case 7:
            sleepTime = 60*30;
            break;
        case 8:
            sleepTime = ONE_HOUR*2;
            break;
        case 9:
            sleepTime = ONE_HOUR*2;
            break;
        case 10:
            sleepTime = ONE_HOUR*2;
            break;
        default:
            sleepTime = ONE_HOUR*4;
    }

    if (rtcData.consecutiveCrashes > 3 || eeprom.debug) {
        dumpToScreen(reason, sleepTime);
    }

    rtcData.nextTime += sleepTime;

    if (eeprom.debug) {
        Serial.println(reason);

        Serial.print("SSID:");
        Serial.println(WiFi.SSID());

        Serial.print("Free heap:");
        Serial.println(system_get_free_heap_size());

        Serial.print("Router MAC Address:");
        Serial.println(WiFi.BSSIDstr());

        Serial.print("IP address:");
        Serial.println(WiFi.localIP());

        Serial.print("Gateway IP:");
        Serial.println(WiFi.gatewayIP());

        Serial.print("RSSI:");
        Serial.println(WiFi.RSSI());

        Serial.print("MAC Address:");
        Serial.println(WiFi.macAddress());

        Serial.print("URL:");
        setURL();
        Serial.println(url);

        Serial.print("Last successful attempt at:");
        Serial.println(rtcData.currentTime);

        Serial.print("Last unsuccessful attempt at:");
        Serial.println(rtcData.currentTime + rtcData.elapsedTime);

        //Serial.print("Next planned wakeup time:");
        //Serial.println(rtcData.nextTime);

        Serial.print("Next attempt in:");
        Serial.print(sleepTime);
        Serial.println(" seconds");
    }

    if (sleepTime > MAX_SLEEP) {
        sleepTime = MAX_SLEEP;
    }

    rtcData.elapsedTime += sleepTime;

    // Update CRC32 of data
    rtcData.crc32 = calculateCRC32(((uint8_t*) &rtcData) + 4, sizeof(rtcData) - 4);

    // Write struct to RTC memory; this if statement has important side-effects; do not remove it!
    if (ESP.rtcUserMemoryWrite(0, (uint32_t*) &rtcData, sizeof(rtcData))) {
        //Serial.println("Write: ");
        //printMemory();
        //Serial.println();
    }

    ESP.deepSleep(sleepTime * 1000000);

}

void sleep() {
    uint32_t sleepTime = rtcData.nextTime - rtcData.currentTime - rtcData.elapsedTime;
    if (sleepTime > MAX_SLEEP) {
        sleepTime = MAX_SLEEP;
    }
    rtcData.elapsedTime += sleepTime;

    // Update CRC32 of data
    rtcData.crc32 = calculateCRC32(((uint8_t*) &rtcData) + 4, sizeof(rtcData) - 4);
    // Write struct to RTC memory
    if (ESP.rtcUserMemoryWrite(0, (uint32_t*) &rtcData, sizeof(rtcData))) {
    }

    if (eeprom.debug) {
        Serial.print("currentTime: ");
        Serial.println(rtcData.currentTime);
        Serial.print("nextTime: ");
        Serial.println(rtcData.nextTime);
        Serial.print("elapsedTime: ");
        Serial.println(rtcData.elapsedTime);
        Serial.print("consecutiveCrashes: ");
        Serial.println(rtcData.consecutiveCrashes);
    }

    if (sleepTime + rtcData.driftSeconds < MIN_SLEEP) {
        if (eeprom.debug) {
            Serial.print("Sleeping for the minimum of");
            Serial.print(MIN_SLEEP);
            Serial.println(" seconds");
            Serial.print("Drift seconds: ");
            Serial.println(rtcData.driftSeconds);
        }
        ESP.deepSleep(MIN_SLEEP * 1000000);
    }
    if (eeprom.debug) {
        Serial.print("sleepTime: ");
        Serial.print(sleepTime);
        Serial.println(" seconds");
        Serial.print("Drift seconds added to the above figure: ");
        Serial.println(rtcData.driftSeconds);
        Serial.print("Time in milliseconds: ");
        Serial.println(ESP.getCycleCount() / 80000);
        Serial.println("");
    }
    ESP.deepSleep((sleepTime + rtcData.driftSeconds) * 1000000);
}

void dumpToScreen(String reason, uint32_t sleepTime) {
    display.init();
    display.setRotation(ROTATION);
    display.fillScreen(GxEPD_WHITE);
    display.setTextColor(GxEPD_BLACK);
    display.setFont(&FreeMonoBold9pt7b);
    display.setCursor(0, 0);
    display.println();

    display.println(reason);

    display.print("SSID:");
    display.println(WiFi.SSID());

    display.print("Router MAC Address:");
    display.println(WiFi.BSSIDstr());

    display.print("IP address:");
    display.println(WiFi.localIP());

    display.print("Gateway IP:");
    display.println(WiFi.gatewayIP());

    display.print("RSSI:");
    display.println(WiFi.RSSI());

    display.print("MAC Address:");
    display.println(WiFi.macAddress());

    display.print("URL:");
    setURL();
    display.println(url);

    display.print("Last successful attempt at:");
    display.println(rtcData.currentTime);

    //display.print("Original planned wakeup time:");
    //display.println(rtcData.nextTime);

    display.print("Last unsuccessful attempt at:");
    display.println(rtcData.currentTime + rtcData.elapsedTime);

    display.print("Next attempt in:");
    display.print(sleepTime);
    display.println(" seconds");

    display.update();
    for (int i = 0; i < 20; i++)
        rtcData.imageHash[i] = -1;
}

void handleRoot() {
    if (eeprom.debug) {
        Serial.println("Received request at /");
    }
    String webPage = "<!DOCTYPE HTML> <head> <script type='text/javascript'> function myFunction() { var copyText = document.getElementById('macaddress'); console.log(copyText); copyText.select(); document.execCommand('copy'); } </script> <style type='text/css'> body { margin: auto; background: #eaeaea; font-family: 'Open Sans', sans-serif; } .info p { text-align:center; color: #999; text-transform:none; font-weight:600; font-size:15px; margin-top:2px } .info i { color:#F6AA93; } h2 { width:100px; margin: 0px auto; } form h1 { font-size: 18px; background: #F6AA93 none repeat scroll 0% 0%; color: rgb(255, 255, 255); padding: 22px 25px; border-radius: 5px 5px 0px 0px; margin: auto; text-shadow: none; text-align:left } form { border-radius: 5px; max-width:700px; width:100%; margin: 10px auto; background-color: #FFFFFF; overflow: hidden; } p span { color: #000; } p { margin: 0px; font-weight: 500; line-height: 2; color:#333; } h1 { text-align:center; color: #666; text-shadow: 1px 1px 0px #FFF; margin:50px 0px 0px 0px } input { border-radius: 0px 5px 5px 0px; border: 1px solid #eee; margin-bottom: 15px; width: 75%; height: 40px; padding: 0px 15px; } input#macaddress { width: 120px; height: 25px; } a { text-decoration:inherit } legend { font-weight: bold; } .form-group { overflow: hidden; clear: both; } i { color:#555; } .contentform { padding: 40px 30px; } .button-contact{ background-color: #81BDA4; color: #FFF; text-align: center; width: 100%; border:0; padding: 17px 25px; border-radius: 0px 0px 5px 5px; cursor: pointer; margin-top: 40px; font-size: 18px; } .leftcontact { width:49.5%; float:left; border-right: 1px dotted #CCC; box-sizing: border-box; padding: 0px 15px 0px 15px; } .rightcontact { width:49.5%; float:right; box-sizing: border-box; padding: 0px 0px 0px 15px; } #sendmessage { border:1px solid #fff; display:none; text-align:center; margin:10px 0; font-weight:600; margin-bottom:30px; background-color: #EBF6E0; color: #5F9025; border: 1px solid #B3DC82; padding: 13px 40px 13px 18px; border-radius: 3px; box-shadow: 0px 1px 1px 0px rgba(0, 0, 0, 0.03); } #sendmessage.show,.show { display:block; } .pure-form input { padding:.5em .6em; display:inline-block; border:1px solid #ccc; box-shadow:inset 0 1px 3px #ddd; border-radius:4px; vertical-align:middle; box-sizing:border-box } .pure-form .pure-checkbox,.pure-form .pure-radio{ margin:.5em 0; display:block } .pure-form label{ margin:.5em 0 .2em } .pure-form fieldset{ margin:0; padding:.35em 0 .75em; border:0 } .pure-form legend{ display:block; width:100%; padding:.3em 0; margin-bottom:.3em; color:#333; border-bottom:1px solid #e5e5e5 } .pure-form .pure-group fieldset{ margin-bottom:10px } .pure-form .pure-group input{ display:block; padding:10px; margin:0 0 -1px; border-radius:0; position:relative; top:-1px } .pure-form .pure-group button{ margin:.35em 0 }";
    webPage += "</style></head><body>";
    webPage += "<h1>Web Configuration</h1>";
    webPage += "<div class='info'>";
    webPage += "<p>MAC Address <input id='macaddress' value='";
    webPage += getMAC();
    webPage += "'></span><i class='fa fa-heart'></i><br/>Firmware Version";
    webPage += FIRMWARE_VERSION;
    webPage += "<br/><button onclick='myFunction()'>Copy MAC Address to clipboard</button></p></div>";
    webPage += "<form method='get' action='submit' class='pure-form'><h1>Please fill out the form to configure your wall-ink device</h1><div class='leftcontact'><fieldset class='form-group'><legend>Wifi Connection</legend><p><label for='ssid0'>Wireless SSID0: </label><br/><input id='ssid0' name='ssid0' value='";
    webPage += eeprom.ssid0;
    webPage += "' length=20></p><p><label for='password0'>Password0: </label><br/><input id='password0' name='password0' value='";
    webPage += eeprom.password0;
    webPage +=   "' length=20></p></fieldset><fieldset class='form-group'><legend>Backup Wifi Connection 1</legend><p><label for='ssid1'>Wireless SSID1: </label><br/><input id='ssid1' name='ssid1' value='";
    webPage += eeprom.ssid1;  
    webPage += "' length=20></p><p><label for=password1>Password1: </label><br/><input id='password1' name='password1' value='";
    webPage += eeprom.password1;
    webPage += "' length=20></p></fieldset></div><div class='rightcontact'><fieldset class='form-group'><legend>Wall Ink Server Settings</legend><p><label for='baseurl'>Base URL: </label><br/><input id='baseurl' name='baseurl' value='";
    webPage += eeprom.baseURL;
    webPage += "' length=100></p><p><label for='imagekey'>Image Key: </label><br/><input id='imagekey' name='imagekey' value='";
    webPage +=  eeprom.imageKey;
    webPage += "' length=100>'</p></fieldset><fieldset class='form-group'><legend>Debug Mode</legend><p><label for='on'>On</label><br/><input name='debug' id='debug' value='1' type='radio'></p><p><label for='off'>Off</label><br/><input name='debug' id='debug' value='0' checked='true' type='radio'></p></fieldset></div><button type='submit' class='button-contact'>Send</button></form></body></html>";
    server.send(200, "text/html", webPage);
}
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
void loop() {
    // wait for WiFi connection
    if((WiFi.status() == WL_CONNECTED)) {

        if (eeprom.debug) {
            Serial.println("WiFi Connection established");
            Serial.print("IP address:");
            Serial.println(WiFi.localIP());
            Serial.print("Gateway IP:");
            Serial.println(WiFi.gatewayIP());
            Serial.print("Subnet Mask:");
            Serial.println(WiFi.subnetMask());
            Serial.print("Time in milliseconds: ");
            Serial.println(ESP.getCycleCount() / 80000);
        }

        if (WiFi.RSSI() < -90) {
            rtcData.errorCode = 1;
            crash("Connection Weak");
        }

        //Save wifi connection info
        strcpy(rtcData.ssid, WiFi.SSID().c_str());
        strcpy(rtcData.password, WiFi.psk().c_str());
        rtcData.channel = WiFi.channel();
        memcpy(rtcData.bssid, WiFi.BSSID(), 6);

        // configure server and url
        setURL();
        Serial.println("URL: ");
        Serial.println(url);

        if (eeprom.debug) {
            Serial.print("[HTTP] begin...\n");
        }

        HTTPClient http;
        http.begin(url);

        if (eeprom.debug) {
            Serial.print("[HTTP] GET...\n");
        }
        // start connection and send HTTP header
        int httpCode = http.GET();
        if (httpCode == 404) {
            rtcData.errorCode = 404;
            crash("Error:404");
        } else if(httpCode == 200) {
            if (eeprom.debug) {
                Serial.print("Time in milliseconds: ");
                Serial.println(ESP.getCycleCount() / 80000);
            }
            uint32_t cursor = 0;
            uint8_t eightPixels;
            boolean initialized = false;
            // get length of document (is -1 when Server sends no Content-Length header)
            int len = http.getSize();
            if (eeprom.debug) {
                Serial.print("File Size: ");
                Serial.println(len);
            }

            //this will happen if the mac address isn't found in the database
            if (len < 50) {
                rtcData.errorCode = 2;
                crash("File too small or not found");
                if (eeprom.debug) {
                    system_get_free_heap_size();
                }
            }

            // create buffer for read
            uint8_t buff[128] = { 0 };

            // get tcp stream
            WiFiClient * stream = http.getStreamPtr();

            //sha1( sha1(raw_image) . sha1(chunk2 . chunk3) . sha1(mac_address) . sha1(image_key) )
            //this will be filled out at various points below.
            //the server does the same thing, and the client compares the results.
            uint8_t* hash = (uint8_t*) malloc(80);
            uint8_t* serverEverythingHash = (uint8_t*) malloc(20);

            // read all data from server
            while(http.connected() && (len > 0 || len == -1)) {
                // get available data size
                size_t size = stream->available();

                if(size) {
                    // read up to 128 byte
                    int c = stream->readBytes(buff, ((size > sizeof(buff)) ? sizeof(buff) : size));
                    for (int offset = 0; offset < c; offset++) {
                        if (!initialized) {           //Grab the stuff off the front of the file
                            initialized = true;
                            uint32_t predictedTime = rtcData.currentTime + rtcData.elapsedTime;

                            //sha1( sha1(chunk 2 . chunk 3) . sha1(mac_address) . sha1(image_key) )
                            //the server does the same thing, and the client compares them
                            sha1(buff + 20, 8, hash);
                            char* mac_char_array = (char*) malloc(20);
                            String mac = WiFi.macAddress();
                            while (mac.indexOf(':') != -1) {
                                mac.remove(mac.indexOf(':'), 1);
                            }
                            mac.toCharArray(mac_char_array, 13);
                            sha1(mac_char_array, strlen(mac_char_array), hash+20);
                            sha1(eeprom.imageKey, strlen(eeprom.imageKey), hash+40);
                            uint8_t* finalTimeHash = (uint8_t*) malloc(20);
                            sha1(hash, 60, finalTimeHash);
                            if (eeprom.debug) {
                                Serial.println("remote timeHash: ");
                                for (int i = 0; i < 20; i++) {
                                    Serial.print(String(buff[i], HEX));
                                }
                                Serial.println("\nlocal timeHash: ");
                                for (int i = 0; i < 20; i++) {
                                    Serial.print(String(finalTimeHash[i], HEX));
                                }
                                Serial.println("");
                                Serial.println("");
                            }
                            bool timeVerified = true;
                            for (int i = 0; i < 20; i++) {
                                if (buff[i] != finalTimeHash[i]) {
                                    timeVerified = false;
                                }
                            }
                            if (!timeVerified) {
                                if (eeprom.debug) {
                                    Serial.println("Time info did not pass verification, sleeping");
                                    Serial.print("Time in milliseconds: ");
                                    Serial.println(ESP.getCycleCount() / 80000);
                                }
                                WiFi.disconnect();
                                delay(10);
                                WiFi.forceSleepBegin();
                                delay(10);
                                rtcData.errorCode = 3;
                                crash("Time data or password failed verification test");
                                sleep();
                            }

                            //protect against replay attacks
                            if (rtcData.currentTime >= *(uint32_t*) (buff + 20)) {
                                rtcData.errorCode = 8;
                                crash("Error 8: Replay attack detected");
                            }

                            rtcData.currentTime = *(uint32_t*) (buff + 20);
                            if (rtcData.nextTime == *(uint32_t*) (buff + 24)) {
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

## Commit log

2017-12-15 fixed a bug with debug code, now ignores the first 8 bytes (these are time information)
    [stream_screen.ino]
2017-12-19 Added code to handle crashes
    [stream_screen.ino]
2017-12-19 Added some debug info, the URL is now autogenerated from the device's MAC address.
2018-01-08 Added note on board version
2018-01-09 WiFi should(?) go to some sort of lower-power state before screen is flashed now
2018-01-12 fixed bug with randomized seed
    [stream_screen.ino]
2018-01-18 changed wifi code to fail on bad connection
    [stream_screen.ino]
2018-01-24 device should now crash if image is an empty file
    [stream_screen.ino]
2018-02-09 Fixed a bug relating to time drift and static images
    [stream_screen.ino]
2018-03-09 Fixed a mysterious wifi bug relating to how WiFiMulti.run() was being called
    [stream_screen.ino]
2018-05-29 Added security, fixed a problem in the decompression algorithm
    [stream_screen.ino]
2018-06-11 CS pin on the screen is now connected to GPIO5
2018-06-18 fixed a bug with the debug code change, form fields should autopopulate now.
    [stream_screen.ino]
2018-06-21 Dean fixed a bug that would sometimes cause the screens to not load an image
    [stream_screen.ino]
2018-06-21 The device no longer displays information when it initially boots
    [stream_screen.ino]
2018-06-21 The device doesn't wait as long to throw errors to the screen as it did before
    [stream_screen.ino]
2018-06-27 Added a couple of yield commands, added extremely basic error reporting
    [stream_screen.ino]
2018-06-27 Fixed a problem where rtcData.numErrors may not have been initialized
    [stream_screen.ino]
2018-06-28 Changed how errors are reported, added a key for error codes
    [stream_screen.ino]
2018-06-28 Fixed some dumb bugs
    [stream_screen.ino]
2018-07-09 Added PCB eagle schematic, board, and gerber files
    [wall-ink.brd, wall-ink.sch]
2018-07-09 Added CAD files for the case
    [back.SLDPRT, back.STL, front.SLDPRT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]
2018-07-10 Added the CAD files for the faceplate
    [faceplate.SLDPRT, faceplate.STL]
2018-07-27 Modified case to better fit the faceplate
    [front.SLDPRT, front.STL]
2018-07-27 Fixed a bug in the previous version that was causing the devices to sleep for a decade at a time
    [stream_screen.ino]
2018-08-09 Changed some error messages
    [stream_screen.ino]
2018-10-30 Fixed an image decompression bug that would occur in certain edge cases
    [stream_screen.ino]
2018-11-02 Removed compression because there was a bug that was causing issues
    [stream_screen.ino]
2018-11-13 Wall-Ink devices now report their screen resolution in the HTTP GET request
2018-11-19 Fixed a bug that was causing error logging to not work
    [stream_screen.ino]
2018-11-21 Fixed issue 4, next attempt seconds should be accurate now.
    [stream_screen.ino]
2018-11-21 changed the amount of time before a screen starts outwardly displaying errors from 20 minutes back to 80 minutes
    [stream_screen.ino]
2018-12-06 Fixed some bugs relating to failed wifi connections and error handling
    [stream_screen.ino]
2019-01-10 Fixed an issue where the device would sometimes go into AP_STA mode instead of STA mode
    [stream_screen.ino]
2019-01-20 Styled the Admin Screen for an easier configuration of the device
    Beside the styling the importand part was to add a MAC Address copy to clipboard functionality, which makes it easier to configure the device on the server
2019-01-28 issue 17: changed the amount of time that the device sleeps for when an error occurs
    [stream_screen.ino]
2019-01-28 Added some reinforcement to the case
    [back.SLDPRT, back.STL, front.SLDPRT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]
2019-04-15 issue 20: modified case design for new HATs
    [back.IGS, back.SLDPRT, back.STEP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]
2019-04-19 issue 20: added adaptor to use new HATs in old cases
    [hat_adapter.IGS, hat_adapter.SLDPRT, hat_adapter.STEP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]
